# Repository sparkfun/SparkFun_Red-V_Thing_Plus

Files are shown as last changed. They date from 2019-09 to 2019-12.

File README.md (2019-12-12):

SparkFun RED-V Thing Plus
========================================

SparkFun RED-V Thing Plus (https://www.sparkfun.com/products/15799)

*[SparkFun RED-V Thing Plus (DEV-15799)](https://www.sparkfun.com/products/15799)*

The SparkFun RED-V (pronounced “red-five”) Thing Plus is a low-cost, development board in our popular Thing Plus footprint and adds in the Freedom E310 core and RISC-V instruction set architecture (ISA). What sets the RED-V Thing Plus apart is the completely open-source approach from hardware to ISA. That means anyone can make full use the microcontroller without requiring royalties, licenses, or non-disclosure agreements.

It utilizes our handy Qwiic Connect System which means no soldering or shields are required to connect it to the rest of your system with plug-and-play I<sup>2</sup>C functionality. Since the Thing Plus footprint is also Feather-compatible, you can take advantage of a shield option in case you didn't want to use our Qwiic Connect System! Additionally, it comes programmed with a simple bootloader. The modern USB-C connector makes it easy to program via the FE310's NXP K22 ARM Cortex-M4 for USB connectivity and operating as a JTAG interface. For more advanced users who prefer to use the power and speed of professional tools, we've also exposed the JTAG connector.  With so much functionality, the SparkFun RED-V Thing Plus is an ideal choice for your RISC-V project.

The on board Freedom E310 (FE310) is the first member of the Freedom Everywhere family of customizable SoCs from SiFive. Designed for microcontroller, embedded, IoT, and wearable applications, the FE310 features SiFive’s E31 CPU Coreplex, a high-performance, 32-bit RV32IMAC core. Running at 320+ MHz, the FE310 is among the fastest microcontrollers in the market. Additional features include a 16KB L1 Instruction Cache, a 16KB Data SRAM scratchpad, hardware multiply/divide, a debug module, flexible clock generation with on-chip oscillators and PLLs, and a wide variety of peripherals including UARTs, QSPI, PWMs, and timers. Multiple power domains and a low-power standby mode ensure a wide variety of applications can benefit from the FE310. The RED-V Thing Plus requires Freedom Studio software or a Zephyr RTOS build environment set up to program the board and interface with it.

Repository Contents
-------------------

* **/Hardware** - Eagle design files (.brd, .sch)

Documentation
--------------

* **[Hookup Guide](https://learn.sparkfun.com/tutorials/red-v-redboard-hookup-guide)** - Basic hookup guide for the SparkFun RED-V Thing Plus.
* **[RED-V Development Guide](https://learn.sparkfun.com/tutorials/red-v-development-guide)** - Getting started with the RED-V in Freedom Studio and Zephyr RTOS.

License Information
-------------------

This product is _**open source**_! 

Please review the LICENSE.md file for license information. 

If you have any questions or concerns on licensing, please contact technical support on our [SparkFun forums](https://forum.sparkfun.com/viewforum.php?f=152).

Distributed as-is; no warranty is given.

- Your friends at SparkFun.

_<COLLABORATION CREDIT>_

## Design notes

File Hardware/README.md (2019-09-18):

SparkFun Redboard Design Files
=====================================

The .sch and .brd files hare are Eagle CAD schematic and PCB design files from SparkFun Electronics.
A freeware version of Eagle can be found [here](http://www.cadsoftusa.com/download-eagle/freeware/).

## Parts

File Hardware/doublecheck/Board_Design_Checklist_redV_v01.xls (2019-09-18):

SECTION | CHECK | STATUS | DEPENDANCY | CORRECT ANSWER | USER | USER-ANSWER | COMMENT | WIKI_LINK
Macro | is_revision | 0
Macro | has_pth | 0
Macro | has_i2c | 1
Macro | has_SPI | 1
Macro | has_1x6_ftdi_header | 0
Macro | has_jumpers | 0
Macro | has_leds | 1
Macro | has_vreg | 1
Macro | has_QFN | 1
Macro | has_SS | 0
Macro | has_multi_sheet | 0
Macro | is_kit | 0
Macro | has_serial | 0
Macro | is_4layer | 0
Macro | has_milling | 0
Macro | has_switchorbutton | 1
Macro | has_collaboration | 0
Schematic | Does the board pass the Schematic Autochecklist ULP? |  |  | YES
Schematic | Are all schematic objects inside the frame? |  |  | YES | andrew.england | YES
Schematic | Is proper attribution given to the original designer? |  |  | YES | andrew.england | YES
Schematic | Is "Revised by: " and the reviser's name present? |  | 2 | YES | andrew.england | *n/a*
Schematic | Have all nets been drawn straight out from pin connections at least one grid space? |  |  | YES | andrew.england | YES
Schematic | Are there any 4-way junctions? |  |  | NO | andrew.england | NO
Schematic | Are junction dots used for all 3-wire connections? |  |  | YES | andrew.england | YES
Schematic | Are the fiducials in the lower right corner? |  |  | YES | andrew.england | YES
Schematic | Are the standoffs in the lower right corner? |  |  | YES | andrew.england | YES
Schematic | Are dashed grey lines ('info' eagle layer 97) used to clearly separate different areas? |  |  | YES | andrew.england | YES
Schematic | Is the version number correct? |  |  | YES | andrew.england | YES
Schematic | Is the version number included on all sheets? |  | 12 | YES | andrew.england | *n/a*
Schematic | Do all GND connections use the GND symbol (oriented downward)? |  |  | YES | andrew.england | YES
Schematic | Do all VCC connections use the VCC symbol (oriented upward)? |  |  | YES | andrew.england | YES
Schematic | Is the VCC range clearly labeled? |  |  | YES | andrew.england | YES
Schematic | Are any jumpers labeled clearly by their function and possible settings? |  | 7 | YES | andrew.england | *n/a*
Schematic | Are any appropriate warnings (voltage conversion, sensitive I/O) labeled? |  |  | YES | andrew.england | YES
Schematic | Are any notes of two versions of the board in the schematic (3.3V regulator vs 5V regulator)? |  |  | YES | andrew.england | n/a
Schematic | Do any part names have '/.~' in them? (Multiple sheets) |  | 12 | NO | andrew.england | *n/a*
Schematic | Have you verified that the BOM *including PCB* (also checking for PROD_ID, NAME, VALUE, PREFIX)? |  |  | YES | andrew.england | YES
Schematic | Do any parts have unnecessary values (Eagle has autoset the package as the value)? |  |  | NO | andrew.england | NO
Schematic | Regarding the voltage regulator, is the input on the LEFT, and the output on the RIGHT? |  | 9 | YES | andrew.england | YES
Schematic | Is the I2C address in the schematic? |  | 4 | YES | andrew.england | n/a
Schematic | Is the I2C pin order correct (GND/VCC/SDA/CLK) and did you consider using a Qwiic connector? |  | 4 | YES | andrew.england | YES |  | https://wiki.sparkfun.com/index.php?title=Eagle_Rules#Pin_Out.2FConnection_Orientation
Schematic | Is the I2C pull-up resistor isolation jumper present? |  | 4 | YES | andrew.england | NO | exists on qwiic slaves | https://wiki.sparkfun.com/index.php?title=Eagle_Rules#Component_Placement
Schematic | Is the SPI pull-up resistor for Chip Select present? |  | 5 | YES | andrew.england | YES |  | https://wiki.sparkfun.com/index.php?title=Eagle_Rules#Component_Placement
Schematic | Is the MISO tri-state buffer included? |  | 5 | YES | andrew.england | NO | copying risc-v schematic | https://wiki.sparkfun.com/index.php?title=Eagle_Rules#Component_Placement
Board | Does the board pass the Board Autochecklist ULP? |  |  | YES | andrew.england | YES |  | https://wiki.sparkfun.com/index.php?title=Qwiic_Standard
Board | If this board is not branded as a Qwicc board, but contains a Qwiic connector, is the connector labeled with “QWIIC” text silk? |  | 4 | YES | andrew.england | YES
Board | Are the inner layers on the correct eagle layers? (2 and 15) |  | 15 | YES | andrew.england | *n/a* |  | https://wiki.sparkfun.com/index.php?title=Eagle_Rules#Board_Creation.2C_Outline
Board | Does your 4 layer board include '1' '2' '3' '4' in the copper of each layer? |  | 15 | YES | andrew.england | *n/a* |  | https://wiki.sparkfun.com/index.php?title=Eagle_Rules#Board_Creation.2C_Outline
Board | If this is a Qwiic board, does it follow the design guidelines for Qwiic boards in the Wiki? |  | 4 | YES | andrew.england | n/a |  | https://wiki.sparkfun.com/index.php?title=Eagle_Rules#Board_Creation.2C_Outline
Board | If this requires very precise dimensions (e.g. USB stick), did you consider GP's tolerances? (dimension=5mils, Vscore=10mils) |  |  |  | andrew.england | YES |  | https://wiki.sparkfun.com/index.php?title=Eagle_Rules#Fab_house_Tolerances
Board | Do all testpoints have a separation of at least 0.1 inch (preferably placed on a 0.05 inch grid)? |  |  | YES | andrew.england | YES |  | https://wiki.sparkfun.com/index.php?title=Eagle_Rules#Board_Creation.2C_Outline
Board | Can standoffs/screws be used clear of other parts? |  |  | YES | andrew.england | YES |  | https://wiki.sparkfun.com/index.php?title=Eagle_Rules#Board_Creation.2C_Outline
Board | Is the FTDI connector accessible (do neighboring parts allow enough space to clear each side)? |  | 6 | YES | andrew.england | *n/a* |  | https://wiki.sparkfun.com/index.php?title=Eagle_Rules#Pin_Out.2FConnection_Orientation
Board | Is the FTDI connector oriented so the FTDI breakout can be slid on properly (IC side up, header side down)? |  | 6 | YES | andrew.england | *n/a* |  | https://wiki.sparkfun.com/index.php?title=Eagle_Rules#Pin_Out.2FConnection_Orientation
Board | Are vias tented correctly? |  |  | YES | andrew.england | YES |  | https://wiki.sparkfun.com/index.php?title=Eagle_Rules#Trace_Routing.2C_Polygon_Pours.2C_and_Vias
Board | If possible, are all overhanging parts on the same edge of the board (this helps with panelization)? |  |  | YES | andrew.england | YES |  | https://wiki.sparkfun.com/index.php?title=Eagle_Rules#Pin_Out.2FConnection_Orientation
Board | If this design requires special ordering or production assembly instructions, have the symbols/packages been added with notes? (PCB thickness, humidity sensitivity, etc.) |  |  | YES | andrew.england | NO
Board | Are any vias intended to be used as PTH headers (they shouldn't be)? |  |  | NO | andrew.england | NO |  | https://wiki.sparkfun.com/index.php?title=Eagle_Rules#Trace_Routing.2C_Polygon_Pours.2C_and_Vias
Board | Is the LED color standard followed? (red for power, blue for STAT, green for TX, yellow for RX) |  | 8 | YES | andrew.england | YES |  | https://wiki.sparkfun.com/index.php?title=Eagle_Rules#Component_Placement
Board | Do parts that need selective solder have a planned nozzle path on layer 48? (valid widths: 0.178", 0,263", 0.354") |  | 11 | YES | andrew.england | *n/a* |  | https://wiki.sparkfun.com/index.php?title=Eagle_Rules#Selective_Soldering
Board | As best as possible, do all SMD pads have only 1 trace entering the pad? |  |  | YES | andrew.england | YES |  | https://wiki.sparkfun.com/index.php?title=Eagle_Rules#PCB_Layout
Board | Are there any natural bridges on SMT components? |  |  | NO | andrew.england | NO |  | https://wiki.sparkfun.com/index.php?title=Eagle_Rules#PCB_Layout
Board | Do V-Scored edges have a 50 mil border free of pads and parts (to prevent cracking on separation)? |  |  | YES | andrew.england | YES
Board | Is the direction of TX/RX serial connections correct? |  | 14 | YES | andrew.england | *n/a*
Board | Are the TX/RX pins of the FTDI properly connected? |  | 6 | YES | andrew.england | *n/a*
Board | Is trace routing up to spec? (to/from center-points, straight lines, 45 angles, 'T' intersections, no right angles or acid traps) |  |  | YES | andrew.england | YES |  | https://wiki.sparkfun.com/index.php?title=Eagle_Rules#PCB_Layout
Board | For thermal considerations, are traces routed away from the component, with symmetrical routing? |  | 10 | YES | andrew.england | YES
Board | Do all footprints pass 1:1 check? (Applies mostly to new components) |  |  | YES | andrew.england | YES
Board | Are all QFN components with 6 or more leads 75 percent pasted on lead pads? (May be contended depending on performance) |  | 10 | YES | andrew.england | NO | 48 qfn is known good | https://wiki.sparkfun.com/index.php?title=Eagle_Rules#Footprints.2FPackages
Board | Are center pad cream apertures properly reduced? (50-75% paste is good) |  | 10 | YES | andrew.england | YES |  | https://wiki.sparkfun.com/index.php?title=Eagle_Rules#Footprints.2FPackages
Board | Is there solder mask between pads on of 11 mil separation and greater? |  |  | YES | andrew.england | YES |  | https://wiki.sparkfun.com/index.php?title=Eagle_Rules#Fab_house_Tolerances
Board | Is there a correct version number in the copper (aligned properly with the edge of the PCB)? |  |  | YES | andrew.england | YES
Board | Does it pass DRC with top/bottom keepout layers on? |  |  | YES | andrew.england | YES
Board | If there are any DRC errors, have they all been approved? |  |  | YES | andrew.england | YES
Board | Are all KIT PTH parts on the correct side with correct masking (e.g. the TSTOP or BSTOP expose the correct side) |  | 13 | YES | andrew.england | *n/a*
Documentation | Is there a note for a 4-layer board (on tDOCU)? |  | 15 | YES | andrew.england | *n/a*
Documentation | Do all packages have NAME and VALUE? |  |  | YES | andrew.england | YES
Documentation | Is there a note for a board thickness other than 0.63 inch? |  |  |  | andrew.england | NO
Documentation | Are measurements included for outer dimension and standoffs (Eagle layer 47)? |  |  | YES | andrew.england | YES
Documentation | Are the board dimensions on 0.05 inch or 0.01 inch grid? |  |  | YES | andrew.england | YES
Documentation | Are routed-out areas labeled 'ROUTE OUT' (on dimension)? |  | 16 | YES | andrew.england | *n/a*
Documentation | Is the designer name included in tDocu? |  |  | YES | andrew.england | YES
Documentation | Is 'Revised by:' and 'Revisor Name' included in tDocu? |  | 2 | YES | andrew.england | *n/a*
Silkscreen/Labeling | Is the name of the board on the board? |  |  | YES | andrew.england | YES |  | https://wiki.sparkfun.com/index.php?title=Eagle_Rules#PCB_Silk
Silkscreen/Labeling | Are all LEDs labeled with their purpose? |  | 8 | YES | andrew.england | YES
Silkscreen/Labeling | Are all PTHs (aka connectors) clearly labeled with their purpose on both sides of the board? |  |  | YES | andrew.england | n/a
Silkscreen/Labeling | Are battery terminals labeled +/- correctly? |  |  | YES | andrew.england | n/a
Silkscreen/Labeling | Are all jumpers labeled? |  | 7 | YES | andrew.england | *n/a*
Silkscreen/Labeling | If it is a 3-way jumper, is there a label on each side of the jumper? |  | 7 | YES | andrew.england | *n/a*
Silkscreen/Labeling | Are all switches/buttons labeled properly? |  | 17 | YES | andrew.england | YES
Silkscreen/Labeling | Are active low pins labeled clearly? |  |  | YES | andrew.england | YES
Silkscreen/Labeling | Are all labels lined up properly and legible? |  |  | YES | andrew.england | YES
Silkscreen/Labeling | Does the FTDI connector have BLK/GRN labeled correctly? |  | 6 | YES | andrew.england | *n/a*
Silkscreen/Labeling | Do all components have polarity or pin 1 labeled? |  |  | YES | andrew.england | YES
Silkscreen/Labeling | Is the polarity label outside of the package for visibility after part population? |  |  | YES | andrew.england | YES
Silkscreen/Labeling | Are there check labels for different versions of the board (3.3V vs 5V)? |  |  | YES | andrew.england | n/a
Silkscreen/Labeling | Is the firmware opensource? If not, did you omit the OSHW Logo? |  | 18 | YES | andrew.england | *n/a*
Silkscreen/Labeling | Is any silkscreen overlaid on vias? |  |  | NO | andrew.england | YES
Silkscreen/Labeling | Is there a URL for any kits or unique boards? |  |  |  | andrew.england | n/a
Special | Are dimension lines properly spaced for V-scoring (lines on a 0.020” center-to-center spacing)? |  |  |  | andrew.england | n/a
Special | On white solder mask pcbs, is there any solder mask between leads on large SMT components? |  |  |  | andrew.england | n/a
Special | Are axes labeled correctly? |  |  |  | andrew.england | n/a
Special | Are there warning labels for high voltage areas? |  |  |  | andrew.england | n/a
END | Thanks for flying with us. Have a great day!! |  |  |  | andrew.england | n/a

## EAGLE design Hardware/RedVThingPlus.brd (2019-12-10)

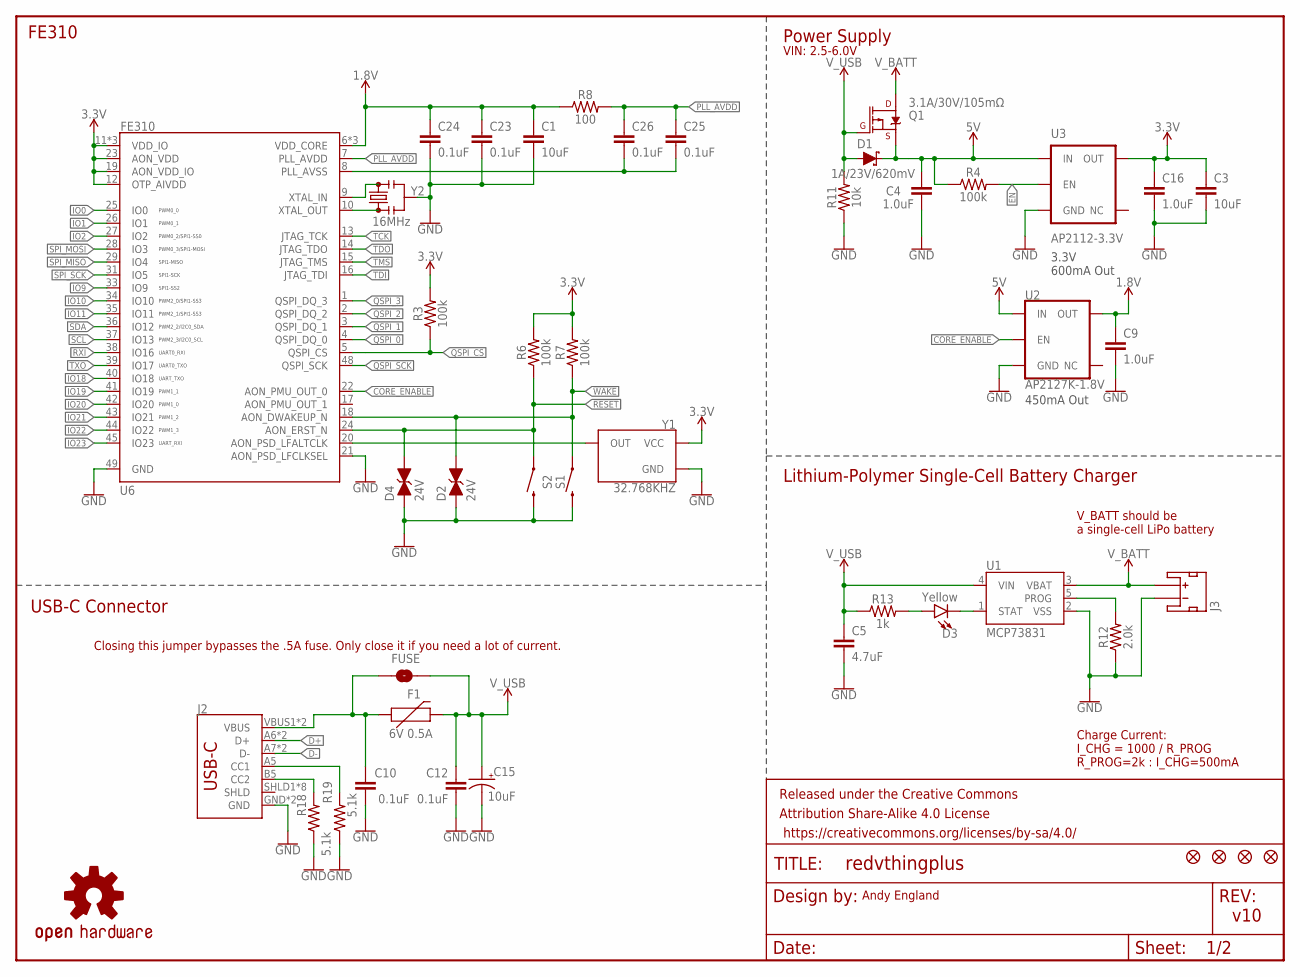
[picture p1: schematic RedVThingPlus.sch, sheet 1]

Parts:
C1, C3: 10uF; 0603
C4, C9, C16: 1.0uF; 0603
C5: 4.7uF; 0603
C10, C12, C23, C24, C25, C26: 0.1uF; 0603
C15: 10uF; EIA3216
D1: 1A/23V/620mV; SOD-323
D2, D4: 24V; 0603
D3: Yellow; LED-0603
F1: 6V 0.5A; 0805
FRAME2: FRAME-LETTER; CREATIVE_COMMONS
FUSE: JUMPER-SMT_2_NO_NO-SILK; SMT-JUMPER_2_NO_NO-SILK
J2: USB Female Type C Connector; USB-C-16P
J3: JST_2MM_MALE; JST-2-SMD
JP8, JP9, JP15, JP16: FIDUCIAL1X2; FIDUCIAL-1X2
Q1: 3.1A/30V/105mΩ; SOT23-3
R3, R4, R6, R7: 100k; 0603
R8: 100; 0603
R11: 10k; 0603
R12: 2.0k; 0603
R13: 1k; 0603
R18, R19: 5.1k; 0603
S1, S2: MOMENTARY-SWITCH-SPST-SMD-4.6X2.8MM; TACTILE_SWITCH_SMD_4.6X2.8MM
U1: MCP73831; SOT23-5
U2: AP2127K-1.8V; SOT23-5
U3: AP2112-3.3V; SOT23-5
U6: FE310; QFN-48-.4MMPITCH
U$16: OSHW-LOGOS; OSHW-LOGO-S
Y1: 32.768KHZ; CRYSTAL-SMD-2X1.2MM
Y2: 16MHz; RESONATOR-SMD-3.2X1.3

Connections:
1.8V: C1.1, C9.1, C23.1, C24.1, R8.1, U2.5 (OUT), U6.6 (VDD_CORE), U6.30 (VDD_CORE), U6.46 (VDD_CORE)
3.3V: C3.1, C16.1, R3.2, R6.2, R7.2, U3.5 (OUT), U6.11 (VDD_IO), U6.12 (OTP_AIVDD), U6.19 (AON_VDD_IO), U6.23 (AON_VDD), U6.32 (VDD_IO), U6.47 (VDD_IO), Y1.4 (VCC); also elsewhere on the board
5V: C4.1, D1.C, Q1.2 (S), R4.1, U2.1 (IN), U3.1 (IN)
!RESET: D4.2 (C), R6.1, S2.1, S2.2 (1), U6.24 (AON_ERST_N); also elsewhere on the board
!WAKE: D2.2 (C), R7.1, S1.1, S1.2 (1), U6.18 (AON_DWAKEUP_N)
CORE_ENABLE: U2.3 (EN), U6.22 (AON_PMU_OUT_0)
D+: J2.A6 (D+), J2.B6 (D+); also elsewhere on the board
D-: J2.A7 (D-), J2.B7 (D-); also elsewhere on the board
EN: R4.2, U3.3 (EN); also elsewhere on the board
GND: C1.2, C3.2, C4.2, C5.2, C9.2, C10.2, C12.2, C15.-, C16.2, C23.2, C24.2, D2.1 (A), D4.1 (A), J2.GND, J2.GND2 (GND), J3.1 (-), R11.1, R12.1, R18.1, R19.1, S1.3 (2), S1.4 (2), S2.3 (2), S2.4 (2), U1.2 (VSS), U2.2 (GND), U3.2 (GND), U6.21 (AON_PSD_LFCLKSEL), U6.49 (GND), Y1.2 (GND), Y2.2; also elsewhere on the board
IO0: U6.25 (IO0); also elsewhere on the board
IO1: U6.26 (IO1); also elsewhere on the board
IO2: U6.27 (IO2); also elsewhere on the board
IO9: U6.33 (IO9); also elsewhere on the board
IO10: U6.34 (IO10); also elsewhere on the board
IO11: U6.35 (IO11); also elsewhere on the board
IO18: U6.40 (IO18); also elsewhere on the board
IO19: U6.41 (IO19); also elsewhere on the board
IO20: U6.42 (IO20); also elsewhere on the board
IO21: U6.43 (IO21); also elsewhere on the board
IO22: U6.44 (IO22); also elsewhere on the board
IO23: U6.45 (IO23); also elsewhere on the board
unnamed: U6.10 (XTAL_OUT), Y2.1
unnamed: U6.9 (XTAL_IN), Y2.3
unnamed: U6.20 (AON_PSD_LFALTCLK), Y1.3 (OUT)
unnamed: R12.2, U1.5 (PROG)
unnamed: C25.2, C26.2, U6.8 (PLL_AVSS)
unnamed: D3.C, U1.1 (STAT)
unnamed: J2.B5 (CC2), R18.2
unnamed: D3.A, R13.2
unnamed: J2.A5 (CC1), R19.2
PLL_AVDD: C25.1, C26.1, R8.2, U6.7 (PLL_AVDD)
QSPI_0: U6.4 (QSPI_DQ_0); also elsewhere on the board
QSPI_1: U6.3 (QSPI_DQ_1); also elsewhere on the board
QSPI_2: U6.2 (QSPI_DQ_2); also elsewhere on the board
QSPI_3: U6.1 (QSPI_DQ_3); also elsewhere on the board
QSPI_CS: R3.1, U6.5 (QSPI_CS); also elsewhere on the board
QSPI_SCK: U6.48 (QSPI_SCK); also elsewhere on the board
RXI: U6.38 (IO16); also elsewhere on the board
SCL: U6.37 (IO13); also elsewhere on the board
SDA: U6.36 (IO12); also elsewhere on the board
SPI_MISO: U6.29 (IO4); also elsewhere on the board
SPI_MOSI: U6.28 (IO3); also elsewhere on the board
SPI_SCK: U6.31 (IO5); also elsewhere on the board
TCK: U6.13 (JTAG_TCK); also elsewhere on the board
TDI: U6.16 (JTAG_TDI); also elsewhere on the board
TDO: U6.14 (JTAG_TDO); also elsewhere on the board
TMS: U6.15 (JTAG_TMS); also elsewhere on the board
TXO: U6.39 (IO17); also elsewhere on the board
VUSB: C10.1, F1.1, FUSE.1, J2.VBUS1 (VBUS), J2.VBUS2 (VBUS)
V_BATT: J3.2 (+), Q1.3 (D), U1.3 (VBAT); also elsewhere on the board
V_USB: C5.1, C12.1, C15.+, D1.A, F1.2, FUSE.2, Q1.1 (G), R11.2, R13.1, U1.4 (VIN); also elsewhere on the board

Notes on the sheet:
Power Supply
FE310
USB-C Connector
Andy England
v10
3.3V 600mA Out
450mA Out
Closing this jumper bypasses the .5A fuse. Only close it if you need a lot of current.
Lithium-Polymer Single-Cell Battery Charger
V_BATT should be a single-cell LiPo battery
Charge Current: I_CHG = 1000 / R_PROG R_PROG=2k : I_CHG=500mA
VIN: 2.5-6.0V

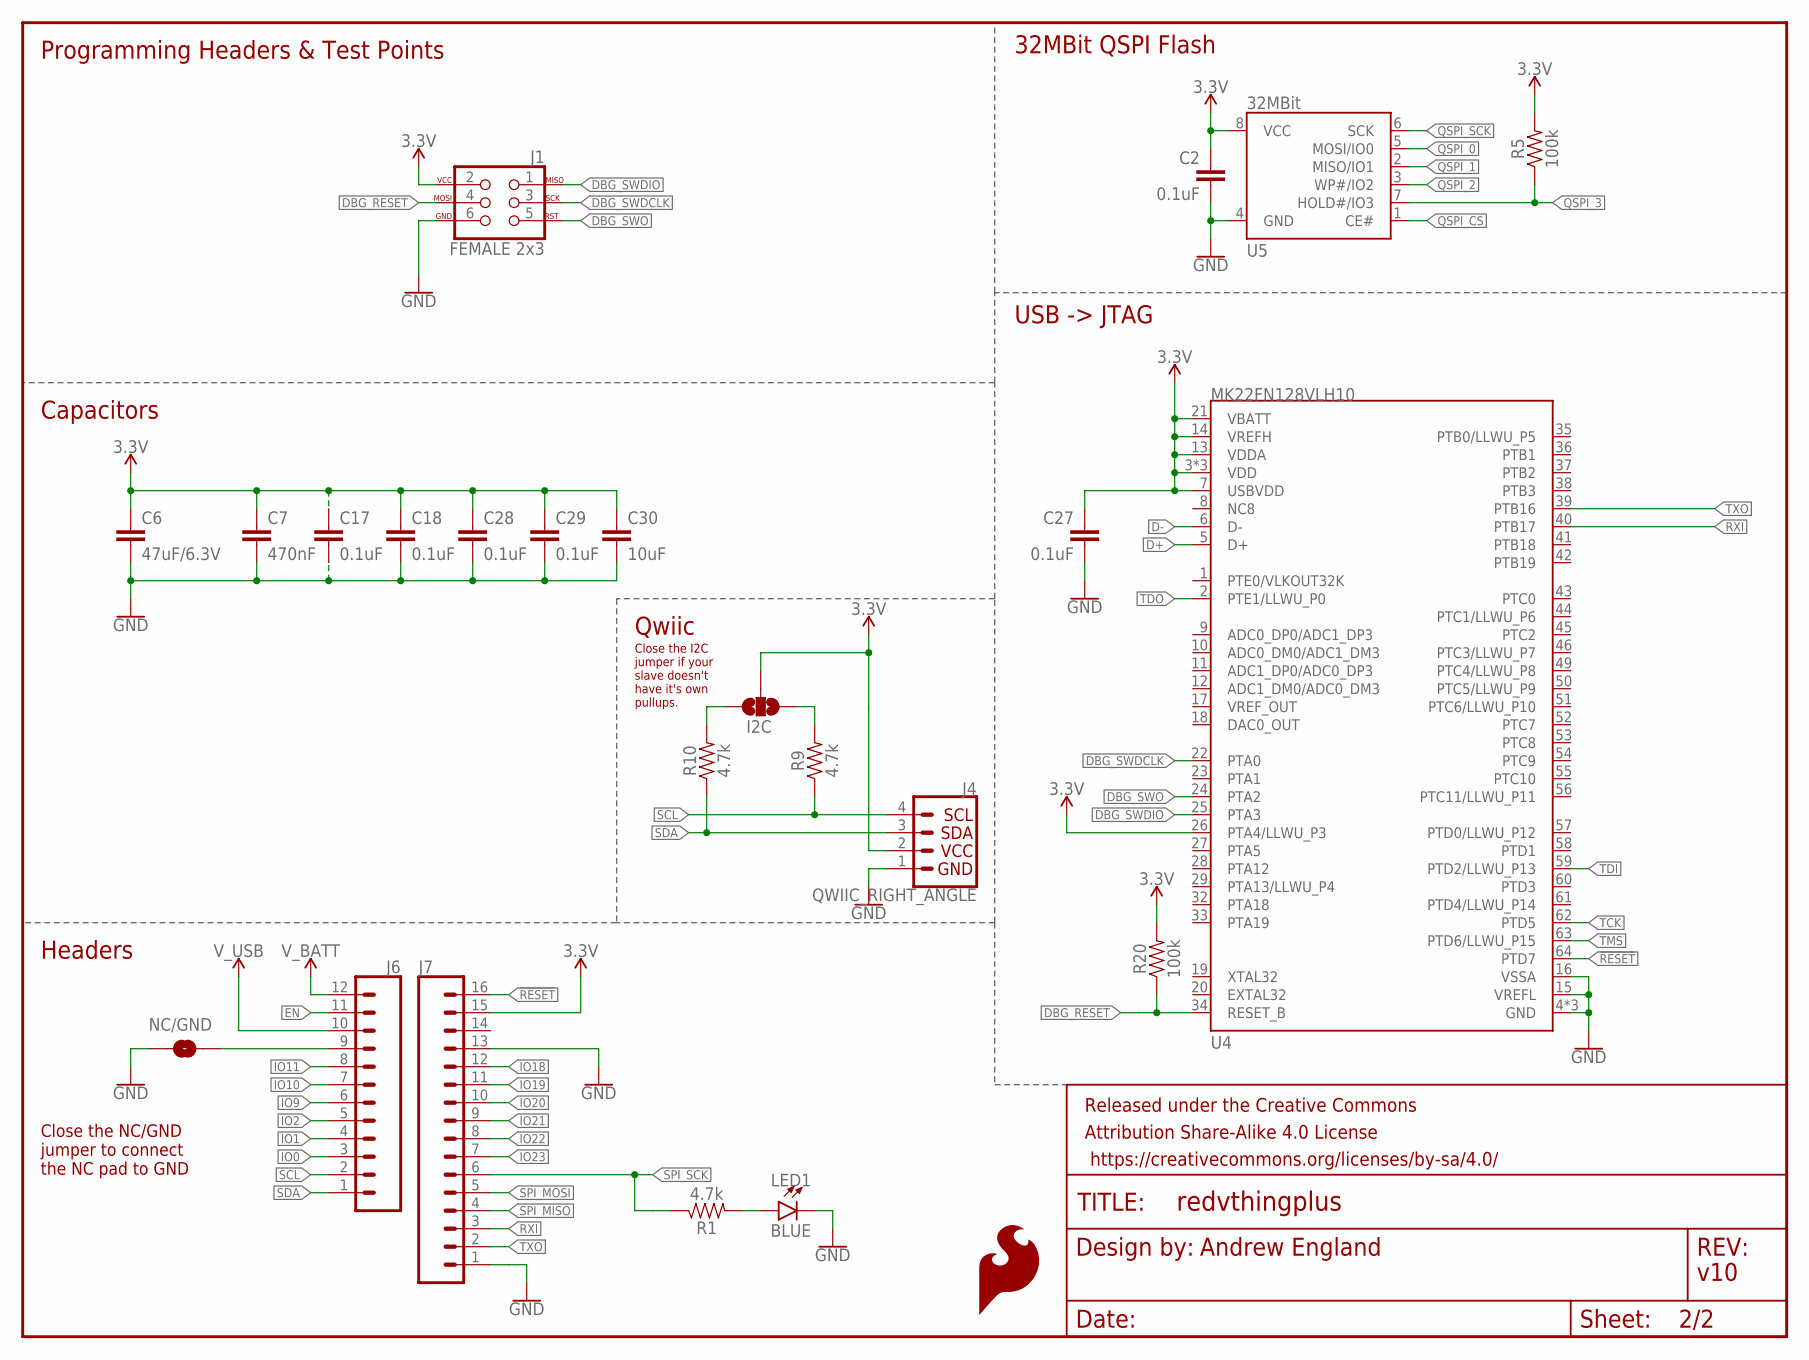
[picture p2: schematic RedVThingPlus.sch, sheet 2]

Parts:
C2, C17, C18, C27, C28, C29: 0.1uF; 0603
C6: 47uF/6.3V; 0805
C7: 470nF; 0603
C30: 10uF; 0603
FRAME1: FRAME-LETTER; CREATIVE_COMMONS
I2C: JUMPER-SMT_3_NO_NO-SILK; SMT-JUMPER_3_NO_NO-SILK
J1: FEMALE 2x3; 2X3_TEST_POINTS
J4: QWIIC_RIGHT_ANGLE; JST04_1MM_RA
J6: CONN_12SM_SQ_NO_SILK; 1X12_SM_SQ_NOSILK
J7: CONN_161X16_SM_SQ_NOSILK; 1X16_SM_SQ_NOSILK
LED1: BLUE; LED-0603
LOGO2: SFE_LOGO_FLAME.2_INCH; SFE_LOGO_FLAME_.2
NC/GND: JUMPER-SMT_2_NO_NO-SILK; SMT-JUMPER_2_NO_NO-SILK
R1, R9, R10: 4.7k; 0603
R5, R20: 100k; 0603
U4: MK22FN128VLH10; LQFP-64
U5: 32MBit; SO08

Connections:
3.3V: C2.1, C6.1, C7.1, C17.1, C18.1, C27.1, C28.1, C29.1, C30.1, I2C.2, J1.2, J4.2, J7.15, R5.2, R20.2, U4.3 (VDD), U4.7 (USBVDD), U4.13 (VDDA), U4.14 (VREFH), U4.21 (VBATT), U4.26 (PTA4/LLWU_P3), U4.30 (VDD), U4.48 (VDD), U5.8 (VCC); also elsewhere on the board
!RESET: J7.16, U4.64 (PTD7); also elsewhere on the board
D+: U4.5 (D+); also elsewhere on the board
D-: U4.6 (D-); also elsewhere on the board
DBG_RESET: J1.4, R20.1, U4.34 (RESET_B)
DBG_SWDCLK: J1.3, U4.22 (PTA0)
DBG_SWDIO: J1.1, U4.25 (PTA3)
DBG_SWO: J1.5, U4.24 (PTA2)
EN: J6.11; also elsewhere on the board
GND: C2.2, C6.2, C7.2, C17.2, C18.2, C27.2, C28.2, C29.2, C30.2, J1.6, J4.1, J7.1, J7.13, LED1.C, NC/GND.1, U4.4 (GND), U4.15 (VREFL), U4.16 (VSSA), U4.31 (GND), U4.47 (GND), U5.4 (GND); also elsewhere on the board
IO0: J6.3; also elsewhere on the board
IO1: J6.4; also elsewhere on the board
IO2: J6.5; also elsewhere on the board
IO9: J6.6; also elsewhere on the board
IO10: J6.7; also elsewhere on the board
IO11: J6.8; also elsewhere on the board
IO18: J7.12; also elsewhere on the board
IO19: J7.11; also elsewhere on the board
IO20: J7.10; also elsewhere on the board
IO21: J7.9; also elsewhere on the board
IO22: J7.8; also elsewhere on the board
IO23: J7.7; also elsewhere on the board
unnamed: LED1.A, R1.2
unnamed: J6.9, NC/GND.2
unnamed: I2C.1, R9.2
unnamed: I2C.3, R10.2
QSPI_0: U5.5 (MOSI/IO0); also elsewhere on the board
QSPI_1: U5.2 (MISO/IO1); also elsewhere on the board
QSPI_2: U5.3 (WP#/IO2); also elsewhere on the board
QSPI_3: R5.1, U5.7 (HOLD#/IO3); also elsewhere on the board
QSPI_CS: U5.1 (CE#); also elsewhere on the board
QSPI_SCK: U5.6 (SCK); also elsewhere on the board
RXI: J7.3, U4.40 (PTB17); also elsewhere on the board
SCL: J4.4, J6.2, R9.1; also elsewhere on the board
SDA: J4.3, J6.1, R10.1; also elsewhere on the board
SPI_MISO: J7.4; also elsewhere on the board
SPI_MOSI: J7.5; also elsewhere on the board
SPI_SCK: J7.6, R1.1; also elsewhere on the board
TCK: U4.62 (PTD5); also elsewhere on the board
TDI: U4.59 (PTD2/LLWU_P13); also elsewhere on the board
TDO: U4.2 (PTE1/LLWU_P0); also elsewhere on the board
TMS: U4.63 (PTD6/LLWU_P15); also elsewhere on the board
TXO: J7.2, U4.39 (PTB16); also elsewhere on the board
V_BATT: J6.12; also elsewhere on the board
V_USB: J6.10; also elsewhere on the board

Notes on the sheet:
Qwiic
Headers
Programming Headers & Test Points
32MBit QSPI Flash
Capacitors
Andrew England
v10
USB -> JTAG
Close the NC/GND jumper to connect the NC pad to GND
Close the I2C jumper if your slave doesn't have it's own pullups.

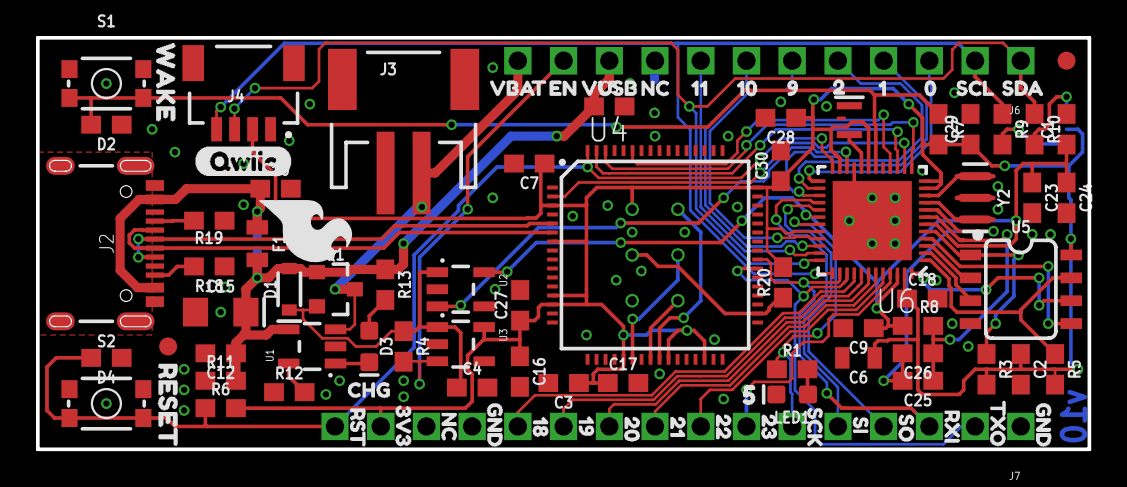
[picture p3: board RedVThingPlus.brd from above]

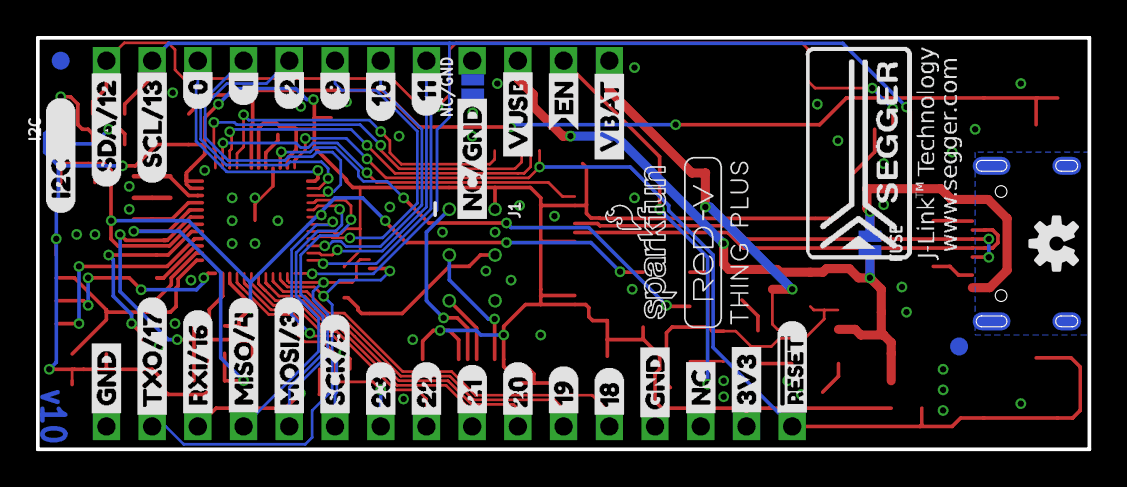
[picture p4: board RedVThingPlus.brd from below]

Board: 2 copper layers, 58.4 x 22.9 mm, 137 parts (40 on the bottom side), 60 nets.

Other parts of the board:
U$1: (QWIIC)
U$2: 96
U$3: 26
U$4: 15
U$5: 04
U$6: SDA9
U$8: TXO1
U$9: 107
U$11: 118
U$12: 1811
U$13: RED#V_THING_PLUS_BOARD_SILK#02#JPG
U$14: 1912
U$15: 2013
U$17: 2114
U$18: 2215
U$19: 2316
U$20: EN18
U$21, U$28: GND0
U$22, U$27: NC17
U$23: RXI2
U$24: SCK5
U$25: SCL10
U$26: VBAT19
U$29: #RESET34
U$30: 3V332
U$31: 3V333
U$32: 015
U$33: 114
U$34: 213
U$35: 912
U$36: 1011
U$37: 1110
U$38: CHG0
U$39: 1828
U$40: 1927
U$41: 2026
U$42: RED#V_THING_PLUS_BOARD_SILK#01#JPG
U$43: 2125
U$44: 2224
U$45: SEGGERLOGO#PNG
U$46: 50
U$47: 2323
U$48: EN8
U$49: ASDFKJGHB#JPG
U$50: I2C_______0
U$51, U$67: GND29
U$52: MISO#421
U$53: MOSI#320
U$54: NC#GND31
U$55: NC30
U$56: RST2
U$57: RXI#1619
U$58: SCK#522
U$59: SCL#1316
U$60: SDA#1217
U$61: SI0
U$62: SO1
U$63: TXO#1718
U$64: VBAT7
U$65: VUSB3
U$66: VUSB9
U$68: RESET1
U$69: WAKE0

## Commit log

2019-09-18 initial commit, schematic refactor from red-v
    [Board_Design_Checklist_redV_v01.xls, RedVThingPlus.brd, RedVThingPlus.sch]
2019-09-20 all components placed, midway through routing
    [RedVThingPlus.brd, RedVThingPlus.sch]
2019-09-24 initial layout complete, needs silk
    [RedVThingPlus.brd, RedVThingPlus.sch]
2019-10-17 v10 changes for Reds design review
    [RedVThingPlus.brd, RedVThingPlus.sch]
2019-10-18 post review changes
    [RedVThingPlus.brd, RedVThingPlus.sch]
2019-10-22 post qc double check changes
    [RedVThingPlus.brd, RedVThingPlus.sch]
2019-10-23 updating to final silk
    [RedVThingPlus.brd, RedVThingPlus.sch]
2019-10-23 updating silk
    [RedVThingPlus.brd]
2019-11-21 small silk update for release
    [RedVThingPlus.brd]
2019-12-10 updating to 100 Ohm resistor on R8
    [RedVThingPlus.brd, RedVThingPlus.sch]

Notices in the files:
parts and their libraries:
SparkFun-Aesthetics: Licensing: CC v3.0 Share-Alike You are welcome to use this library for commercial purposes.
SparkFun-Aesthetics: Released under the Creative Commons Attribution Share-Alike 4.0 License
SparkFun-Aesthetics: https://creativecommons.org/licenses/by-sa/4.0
